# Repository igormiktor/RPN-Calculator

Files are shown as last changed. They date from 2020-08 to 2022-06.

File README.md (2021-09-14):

# RPN-Calculator
An ATmega328-based RPN calculator in assembler.

This creates a simple four-function (+, - , *, /) RPN calculator out of a bare ATmega328p chip that is
wired to a 4x4 button keypad (with classic row-column wiring) and a 2x16 LCD, all powered by a 9V battery.

The calculator implements 32-bit signed integer arithmetic (sorry, no floating point) and a traditional
four-level RPN stack (X, Y, Z, and T as in the classic HP calculators).  The LCD displays
the RPN X register on the lower row and the RPN Y register on the upper row.

There are two LEDs.  They both flash at start-up just to confirm operation.  While using the calculator, the
green LED lights while a number is being entered.  The red LED lights up when an overflow occurs (and the
word "Overflow" displays on the lower row of the LCD).

The keypad is set up as follows:

| | Col 1 | Col 2 | Col 3 | Col 4 |
| :---: | :---: | :---: | :---: | :---: |
| **Row 1** | 1 | 2 | 3 | / |
| **Row 2** | 4 | 5 | 6 | x |
| **Row 3** | 7 | 8 | 9 | - |
| **Row 4** | +/- | 0 | Enter | + |

The code detects key presses by polling (perhaps to be replaced
in the future by an interrupt handler).  Keys are dispatched
using a jump table with the addresses of 16 key-handling functions
and using the jump table to indirect-call to the appropriate one.  

Double-word (32-bit) signed
arithmetic is implemented manually in assembler, as is conversion
of 32-bit quantities to decimal ASCII strings for display.

A schematic of the circuit and a Fritzing wiring diagram (both in PDF) are available in the Schematic folder, along with the Fritzing file.

Various design notes appear in the Notes folder.

The Images directory has photos of the calculator.

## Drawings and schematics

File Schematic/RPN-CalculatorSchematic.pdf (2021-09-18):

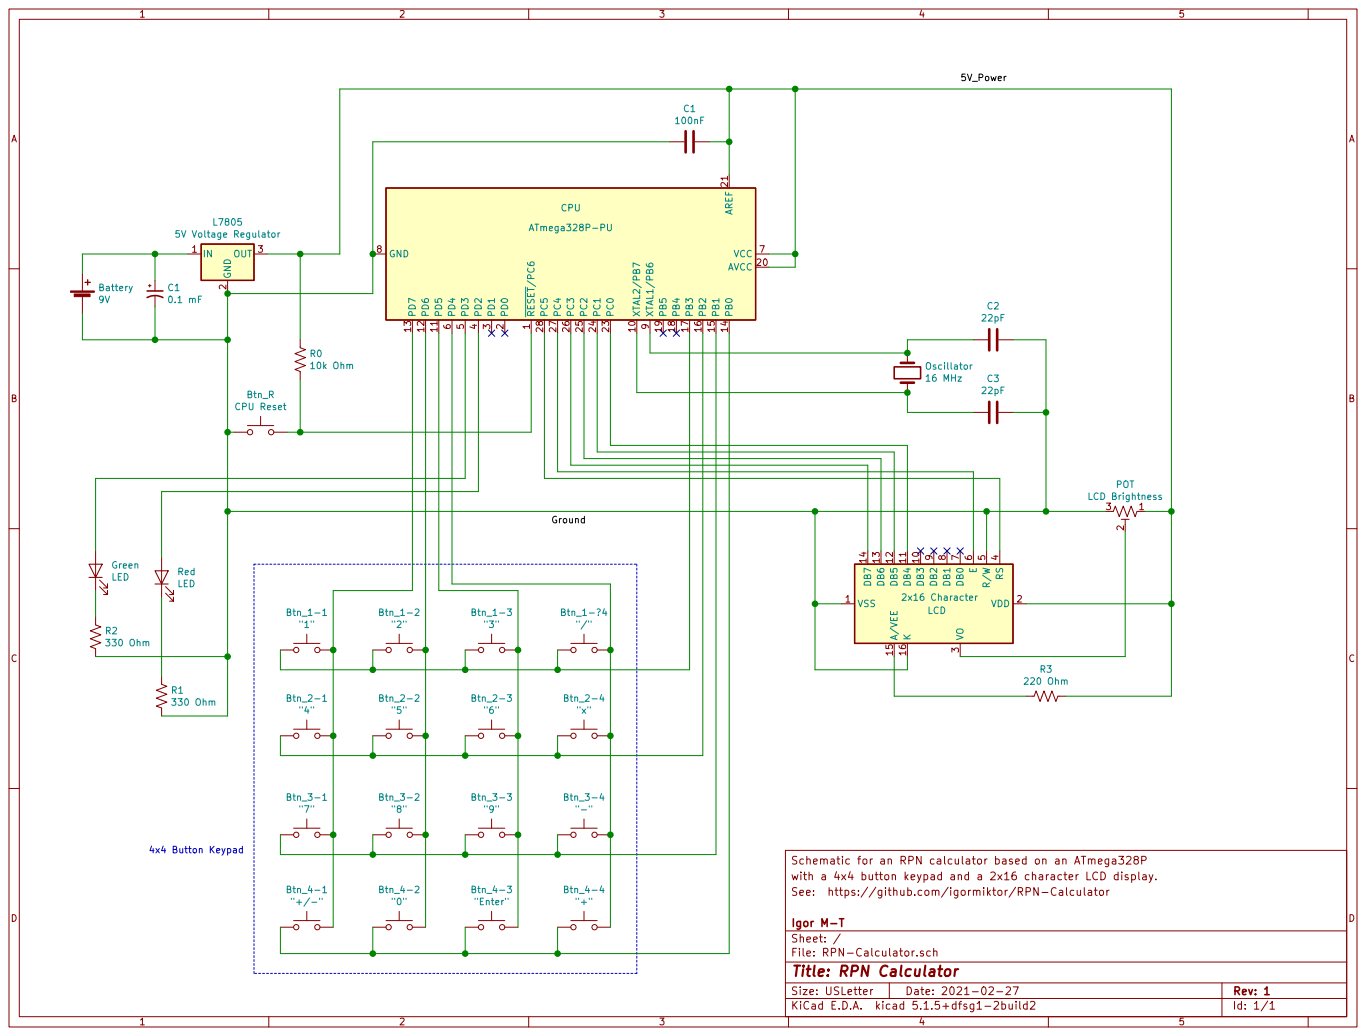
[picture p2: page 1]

Schematic for an RPN calculator based on an ATmega328P
with a 4x4 button keypad and a 2x16 character LCD display.

Btn_4-2 | "Enter" | "+"

See: https://github.com/igormiktor/RPN-Calculator

Igor M-T
Id: 1/1 Title: RPN Calculator File: RPN-Calculator.sch Sheet: /

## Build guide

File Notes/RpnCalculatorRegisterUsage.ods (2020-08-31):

Register → | R0 | R1 | R2 | R3 | R4 | R5 | R6 | R7 | R8 | R9 | R10 | R11 | R12 | R13 | R14 | R15 | R16 | R17 | R18 | R19 | R20 | R21 | R22 | R23 | R24 | R25 | R26 | R27 | R28 | R29 | R30 | R31
 |  |  |  |  |  |  |  |  |  |  |  |  |  |  |  |  |  |  |  |  |  |  |  |  |  |  | XL | XH | YL | YH | ZL | ZH
Aliases → |  |  |  |  |  | DisplayTmp | Scratch0 | Scratch1 | Scratch2 | Scratch3 | NbrByte0 | NbrByte1 | NbrByte2 | NbrByte3 | Loop1 | SREG | Tmp1 DWMSOuter | Tmp2 | Key | State |  |  | ArgByte0 10ths | ArgByte1 DTSOuter | ArgByte2 DTSInnerL DelayUsL MillisL | ArgByte3 DTSInnerH DelayUsH MillisH | DWMSInnerL | DWMSInnerH
Subroutine ↓
Main
configureKeypad |  |  |  |  |  |  |  |  |  |  |  |  |  |  |  |  | U i |  |  |  |  |  |  |  | C | C
convertDwordToAscStr |  |  |  |  |  |  | U C | C | C | C |  |  |  |  |  |  | U |  |  |  |  |  | I P | I P | I P | I P |  |  |  |  | U p | U p
convertDwordToBcdArray |  |  |  |  |  |  | U | U | U | U |  |  |  |  |  |  | U |  |  |  |  |  | I C | I C | I C | I C |  |  |  |  | P | P
delayMicroSeconds |  |  |  |  |  |  |  |  |  |  |  |  |  |  |  |  |  |  |  |  |  |  |  |  | I U i | I U i
delayMilliSeconds |  |  |  |  |  |  |  |  |  |  |  |  |  |  |  |  | U i |  |  |  |  |  |  |  | I U i | I U i | U i | U i
delayTenthsOfSeconds |  |  |  |  |  |  |  |  |  |  |  |  |  |  |  |  |  |  |  |  |  |  | I U | U i | U i | U i
displayArgByte |  |  |  |  |  | C | C | C | C | C |  |  |  |  | C |  | C |  |  |  |  |  | C | C | C | C |  |  |  |  | C | C
displayEntryNbr |  |  |  |  |  | C | C | C | C | C |  |  |  |  | C |  | C |  |  |  |  |  | C | C | C | C |  |  |  |  | C | C
dispatchKey |  |  |  |  |  |  |  |  |  |  |  |  |  |  |  |  |  | U | I U |  |  |  |  |  |  |  | U p | U p |  |  | U p | U p
displayMsgOnLcd |  |  |  |  |  | C |  |  |  |  |  |  |  |  | U |  | U i |  |  |  |  |  | U |  |  |  |  |  |  |  | I U p | I U p
displayRpnX |  |  |  |  |  | C | C | C | C | C |  |  |  |  | C |  | C |  |  |  |  |  | C | C | C | C |  |  |  |  | C | C
displayRpnY
displayRpnY |  |  |  |  |  | C | C | C | C | C |  |  |  |  | C |  | C |  |  |  |  |  | C | C | C | C |  |  |  |  | C | C
doDword2sComplement |  |  |  |  |  |  |  |  |  |  |  |  |  |  |  |  |  |  |  |  |  |  | I O | I O | I O | I O
doKeyHit |  |  |  |  |  |  |  |  |  |  |  |  |  |  |  |  | C | C | C |  |  |  |  |  | U i C | U i C | C | C |  |  | C | C
doKeyNN |  |  |  |  |  |  |  |  |  |  |  |  |  |  |  |  |  | T |  |  |  |  | T | T
doNumericKey |  |  |  |  |  |  |  |  |  |  | I O | I O | I O | I O | C |  | C |  | I U | I O |  |  | U C | U C | U C | U C | C | C |  |  | C | C
doOverflow |  |  |  |  |  | C |  |  |  |  |  |  |  |  | C |  | C |  |  |  |  |  | U C | U C | C | C
getOneDecimalDigit |  |  |  |  |  |  | I | I | I | I |  |  |  |  |  |  | U |  |  |  |  |  | I O | I O | I O | I O |  |  |  |  | U p | U p
initializeLcd |  |  |  |  |  | C |  |  |  |  |  |  |  |  |  |  | C |  |  |  |  |  | U I C |  | C | C | C | C
initStaticData |  |  |  |  |  |  |  |  |  |  |  |  |  |  |  |  | U i | U |  |  |  |  |  |  |  |  | U p | U p |  |  | U p | U p
multiplyBy10 |  |  |  |  |  | C | I O | I O | I O | I O |  |  |  |  | C |  | U C |  |  |  |  |  | C | C | C | C
rollRpnStackDown |  |  |  |  |  |  |  |  |  |  |  |  |  |  | U |  | U i |  |  |  |  |  |  |  |  |  | U p | U p |  |  | U p | U p
rollRpnStackUp |  |  |  |  |  |  |  |  |  |  |  |  |  |  | U |  | U i |  |  |  |  |  |  |  |  |  | U p | U p |  |  | U p | U p
scanKeyPad |  |  |  |  |  |  |  |  |  |  |  |  |  |  |  |  | U i C |  | O |  |  |  |  |  | C | C
sendCmdToLcd |  |  |  |  |  | U |  |  |  |  |  |  |  |  |  |  | C |  |  |  |  |  | I U
sendDataToLcd |  |  |  |  |  | U |  |  |  |  |  |  |  |  |  |  | C |  |  |  |  |  | I U
setLcdRowCol |  |  |  |  |  |  |  |  |  |  |  |  |  |  |  |  | C |  |  |  |  |  | I U i | I U i
write4BitsToLcd |  |  |  |  |  |  |  |  |  |  |  |  |  |  |  |  | U i |  |  |  |  |  | I U i |  | C | C
doChangeSignKey |  |  |  |  |  | C | C | C | C | C | I O | I O | I O | I O | C |  | C |  |  | I |  |  | U | U | U | U |  |  |  |  | C | C
doEnterKey

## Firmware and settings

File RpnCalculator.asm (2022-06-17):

; ***********************************************************************************
;
;    An RPN calculator made with a 4x4 KeyPad and an LCD display
;
;    The MIT License (MIT)
;
;    Copyright (c) 2022 Igor Mikolic-Torreira
;
;    Permission is hereby granted, free of charge, to any person obtaining a copy
;    of this software and associated documentation files (the "Software"), to deal
;    in the Software without restriction, including without limitation the rights
;    to use, copy, modify, merge, publish, distribute, sublicense, and/or sell
;    copies of the Software, and to permit persons to whom the Software is
;    furnished to do so, subject to the following conditions:
;
;    The above copyright notice and this permission notice shall be included in all
;    copies or substantial portions of the Software.
;
;    THE SOFTWARE IS PROVIDED "AS IS", WITHOUT WARRANTY OF ANY KIND, EXPRESS OR
;    IMPLIED, INCLUDING BUT NOT LIMITED TO THE WARRANTIES OF MERCHANTABILITY,
;    FITNESS FOR A PARTICULAR PURPOSE AND NONINFRINGEMENT. IN NO EVENT SHALL THE
;    AUTHORS OR COPYRIGHT HOLDERS BE LIABLE FOR ANY CLAIM, DAMAGES OR OTHER
;    LIABILITY, WHETHER IN AN ACTION OF CONTRACT, TORT OR OTHERWISE, ARISING FROM,
;    OUT OF OR IN CONNECTION WITH THE SOFTWARE OR THE USE OR OTHER DEALINGS IN THE
;    SOFTWARE.
;
; ***********************************************************************************



.device "ATmega328p"


; ++++++++++++++++++++++++++++++++++++++++++++++++++++++++++++++++++++
; ++++++++++++++++++++++++++++++++++++++++++++++++++++++++++++++++++++
;
;  P I N - O U T
;
; ++++++++++++++++++++++++++++++++++++++++++++++++++++++++++++++++++++
; ++++++++++++++++++++++++++++++++++++++++++++++++++++++++++++++++++++
;
; ATmega328p Package = 28-pin-PDIP
; 1: Reset                                      --> Reset switch
; 2: PD0 RXD0 PCINT16
; 3: PD1 TXD0 PCINT17
; 4: PD2 INT0 PCINT18                           --> Red LED
; 5: PD3 INT1 OC2B PCINT19                      --> Green LED
; 6: PD4 T0 XCK0 PCINT20                        --> Keypad Column 4
; 7: Vcc                                        --> +5V
; 8: Gnd                                        --> Ground
; 9: PB6 TOSC1 XTAL1 PCINT6                     --> 16 MHz Oscillator
; 10: PB7 TOSC2 XTAL2 PCINT7                    --> 16 MHz Oscillator
; 11: PD5 T1 OC0B PCINT21                       --> Keypad Column 3
; 12: PD6 AIN0 OC0A PCINT22                     --> Keypad Column 2
; 13: PD7 AIN1 PCINT23                          --> Keypad Column 1
; 14: PB0 ICP1 CLKO PCINT0                      --> Keypad Row 4
; 15: PB1 OC1A PCINT1                           --> Keypad Row 3
; 16: PB2 SS OC1B PCINT2                        --> Keypad Row 2
; 17: PB3 MOSI OC2A PCINT3                      --> Keypad Row 1
; 18: PB4 MISO PCINT4
; 19: PB5 USCK PCINT5
; 20: AVCC                                      --> +5V
; 21: AREF                                      --> +5V
; 22: Gnd                                       --> Ground
; 23: PC0 ADC0 PCINT8                           --> LCD Pin D4 (Data)
; 24: PC1 ADC1 PCINT9                           --> LCD Pin D5 (Data)
; 25: PC2 ADC2 PCINT10                          --> LCD Pin D6 (Data)
; 26: PC3 ADC3 PCINT11                          --> LCD Pin D7 (Data)
; 27: PC4 ADC4 SDA PCINT12                      --> LCD Pin E  (Enable)
; 28: PC5 ADC5 SCL PCINT13                      --> LCD Pin RS (Data/Cmd Select)



; ++++++++++++++++++++++++++++++++++++++++++++++++++++++++++++++++++++
; ++++++++++++++++++++++++++++++++++++++++++++++++++++++++++++++++++++
;
;  P O R T S   A N D   P I N S
;
; ++++++++++++++++++++++++++++++++++++++++++++++++++++++++++++++++++++
; ++++++++++++++++++++++++++++++++++++++++++++++++++++++++++++++++++++

; Red LED pin
.equ pRedLedDirD                    = DDRD
.equ pRedLedDirDBit                 = DDD2
.equ pRedLedPort                    = PORTD
.equ pRedLedPortBit                 = PORTD2
.equ pRedLedPin                     = PIND
.equ pRedLedPinBit                  = PIND2

; Green LED pin
.equ pGreenLedDirD                  = DDRD
.equ pGreenLedDirDBit               = DDD3
.equ pGreenLedPort                  = PORTD
.equ pGreenLedPortBit               = PORTD3
.equ pGreenLedPin                   = PIND
.equ pGreenLedPinBit                = PIND3


; LCD uses pins PC0-PC5

; LCD data (register) select pin
.equ pLcdDataSelectDirD             = DDRC
.equ pLcdDataSelectDirDBit          = DDC5
.equ pLcdDataSelectPort             = PORTC
.equ pLcdDataSelectPortBit          = PORTC5

; LCD enable pin
.equ pLcdEnableDirD                 = DDRC
.equ pLcdEnableDirDBit              = DDC4
.equ pLcdEnablePort                 = PORTC
.equ pLcdEnablePortBit              = PORTC4

; LCD data 7 pin
.equ pLcdD7DirD                     = DDRC
.equ pLcdD7DirDBit                  = DDC3
.equ pLcdD7Port                     = PORTC
.equ pLcdD7PortBit                  = PORTC3

; LCD data 6 pin
.equ pLcdD6DirD                     = DDRC
.equ pLcdD6DirDBit                  = DDC2
.equ pLcdD6Port                     = PORTC
.equ pLcdD6PortBit                  = PORTC2

; LCD data 5 pin
.equ pLcdD5DirD                     = DDRC
.equ pLcdD5DirDBit                  = DDC1
.equ pLcdD5Port                     = PORTC
.equ pLcdD5PortBit                  = PORTC1

; LCD data 4 pin
.equ pLcdD4DirD                     = DDRC
.equ pLcdD4DirDBit                  = DDC0
.equ pLcdD4Port                     = PORTC
.equ pLcdD4PortBit                  = PORTC0



; Keypad uses D4-D7 (columns) and B0-3 (rows)

; Keypad row pins are Port B pins 0-3
.equ pRowDirD                       = DDRB
.equ pRowPort                       = PORTB
.equ pRowPin                        = PINB
.equ kRowBitsOnes                   = 0x0F
.equ kRowBitsZeros                  = 0xF0
; Keypad row pin bits
.equ kRow1                          = 3
.equ kRow2                          = 2
.equ kRow3                          = 1
.equ kRow4                          = 0

; Keypad column pins are Port D pins 4-7
.equ pColDirD                       = DDRD
.equ pColPort                       = PORTD
.equ pColPin                        = PIND
.equ kColBitsOnes                   = 0xF0
.equ kColBitsZeros                  = 0x0F
; Keypad columns pin bits
.equ kCol1                          = 7
.equ kCol2                          = 6
.equ kCol3                          = 5
.equ kCol4                          = 4




; ++++++++++++++++++++++++++++++++++++++++++++++++++++++++++++++++++++
; ++++++++++++++++++++++++++++++++++++++++++++++++++++++++++++++++++++
;
;  C O N S T A N T S
;
; ++++++++++++++++++++++++++++++++++++++++++++++++++++++++++++++++++++
; ++++++++++++++++++++++++++++++++++++++++++++++++++++++++++++++++++++

; Timer constants
.equ kTimer1At1Hz                   = 62449     ; "Top" value for 1Hz output with prescalar of 256
.equ kTimer1At2Hz                   = 31225     ; "Top" value for 2Hz output with prescalar of 256
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

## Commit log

2020-08-27 Initial code commit
    [Calculator.fzz, RpnCalculatorRegisterUsage.ods]
2020-08-28 Add Fritzing schematic and PDF image
    [Calculator.fzz]
2020-08-28 Fix connectors in schematic
    [Calculator.fzz]
2020-08-28 Clean up connections in schematic
    [Calculator.fzz]
2020-08-28 Move register assignments from r24-r27 to r22-r25 (avoid XH:XL)
    [RpnCalculator.asm]
2020-08-29 Clean up connector layout
    [Calculator.fzz]
2020-08-29 Recreate schematic with 180-rotation
    [Calculator.fzz]
2020-08-29 Correct order in which RPN stack was rolled down
    [RpnCalculator.asm]
2020-08-29 Fix register collision by re-ordering calls
    [RpnCalculator.asm]
2020-08-30 Update register usage
    [RpnCalculatorRegisterUsage.ods]
2020-08-30 Rename stack rolling routines to standard names
    [Calculator.old.fzz, Calculator2.fzz]
2020-08-30 Fix digit entry to avoid double stack lift if Enter followed by digit.
    [RpnCalculator.asm]
2020-08-30 Fix end number entry code
    [RpnCalculator.asm]
2020-08-30 Fix assignment of rDelayUsH:rDelayUsL
    [RpnCalculator.asm]
2020-08-31 Remove obsolete files
    [Calculator.old.fzz, Calculator2.fzz]
2020-08-31 Update table of register usage
    [RpnCalculatorRegisterUsage.ods]
2020-09-01 Correct carry to overflow flag
    [RpnCalculator.asm]
2020-09-02 Corrected some skip conditionals; improve clarity of comments on these.
    [RpnCalculator.asm]
2020-09-04 Correct to get sign from an original addend
    [RpnCalculator.asm]
2020-09-04 Replace call with rcall whenever appropriate or possible
    [RpnCalculator.asm]
2020-09-05 Use green LED to indicate number entry mode
2020-09-05 Correct sbi/cbi -> sbr/cbr when dealing with registers
    [RpnCalculator.asm]
2020-09-06 Move LCD-related arguments to new registers to avoid collisions
    [RpnCalculator.asm]
2020-09-06 Fix one missed rArgByte1 -> rLcdArg1 conversion
    [RpnCalculator.asm]
2020-09-06 Create macros for on/off the LEDs and use them
2020-09-06 Turn on Red LED for overflow
2020-09-07 Oops -- missed some add w/carry. Fix add -> adc
    [RpnCalculator.asm]
2020-09-11 Fix error in comment
    [RpnCalculator.asm]
2020-09-12 Fix remainder in case of negative quotient
    [RpnCalculator.asm]
2020-09-12 Add timer-driven watch icons to show calculator is alive
2020-09-12 Fix so overflow msg doesn't overwrite watch icons
    [RpnCalculator.asm]
2020-09-13 Fix macro name throughout
    [RpnCalculator.asm]
2020-09-15 Fix number entry for negative numbers
    [RpnCalculator.asm]
2020-09-18 Correct timer count setting
    [RpnCalculator.asm]
2020-09-18 Fix up whitespace and alignment of text
    [RpnCalculator.asm]
2020-09-18 Make comments correct and accurate
    [RpnCalculator.asm]
2020-09-19 Document pin-out connections
2020-09-19 Document non-digital pin connections
2020-09-28 Fix keypad table description
    [RpnCalculator.asm]
2020-11-29 Fix typo in header comments
    [RpnCalculator.asm]
2020-11-29 Clarify pin-out packaging
2020-12-04 Complete pin-out comments
2021-09-14 Add proper schematic
2021-09-14 Mention revised schematics in README
2021-09-14 Correct comments describing register usage
    [RpnCalculator.asm]
2021-09-18 Correct schematic label on button '9'
